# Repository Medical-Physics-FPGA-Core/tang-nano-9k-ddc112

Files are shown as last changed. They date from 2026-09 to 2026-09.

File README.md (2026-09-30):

# tang-nano-9k-ddc112

FPGA controller and Verilog/SystemVerilog readout implementation for the Texas Instruments DDC112 dual-channel 20-bit current-input ADC using the Sipeed Tang Nano 9K and Gowin FPGA.

This project is intended as a minimal working example for medical physics instrumentation and detector readout experiments.

## Status

- DVALID falling-edge detection confirmed
- DXMIT control implemented
- 40 DCLK pulse readout implemented
- DOUT response to photodiode light confirmed on oscilloscope
- CH1 / CH2 readout confirmed

## Hardware

- Sipeed Tang Nano 9K
- TI DDC112
- Photodiode input
- External level shifting may be required depending on logic levels

### Complete prototype
<p align="center">
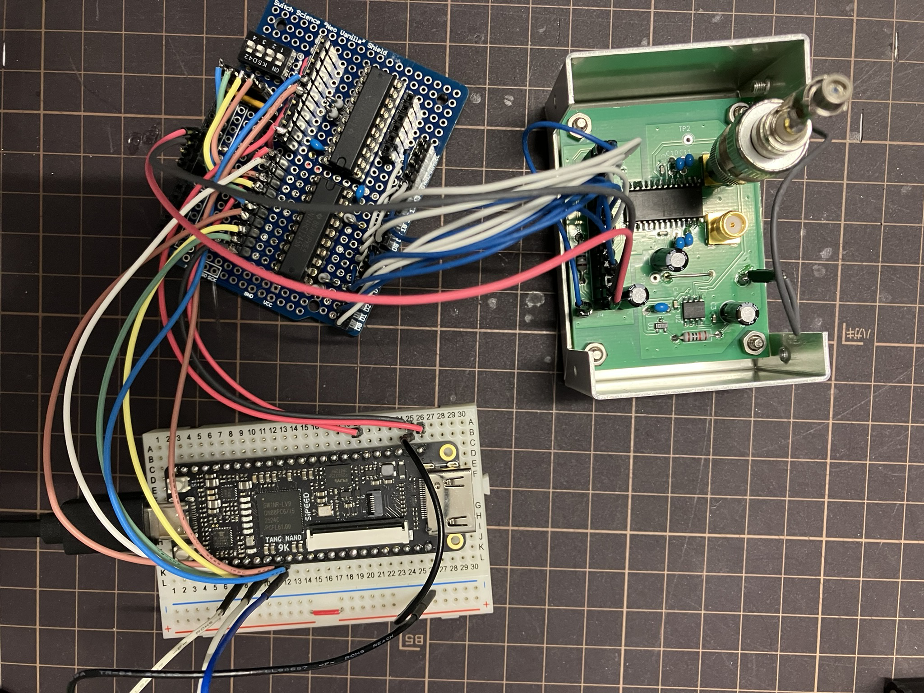
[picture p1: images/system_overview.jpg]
  
</p>
Tang Nano 9K FPGA controller connected to the custom DDC112 analog front-end.

### Custom DDC112 board
<p align="center">
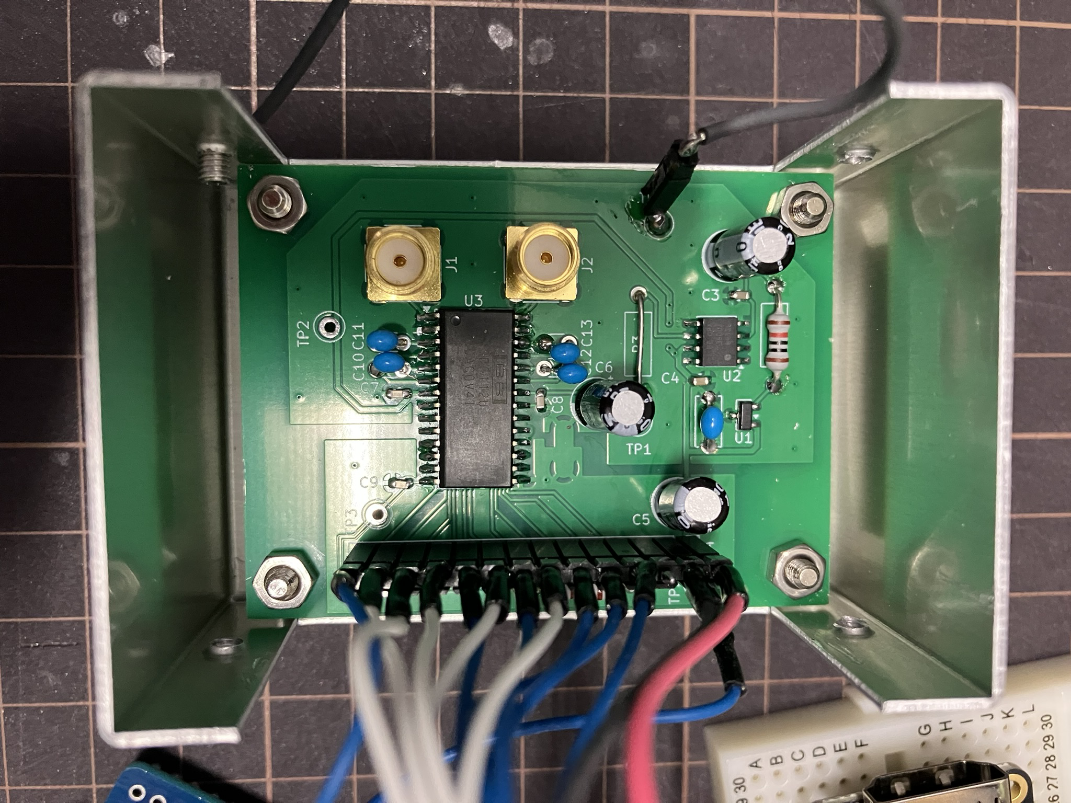
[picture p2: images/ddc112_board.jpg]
  
</p>
Custom PCB based on the Texas Instruments DDC112 dual-channel current-input ADC.

<!-- <img width="1536" height="2048" alt="IMG_5650" src="https://github.com/user-attachments/assets/f4167270-3db4-4d87-b112-6cfbf8c4dc7e" /> --->

## Notes

This repository contains experimental FPGA readout code developed for medical physics instrumentation research.

This is an experimental implementation, not an official TI reference design.
Timing and pin assignments should be verified for each hardware setup.

Constraint files are currently placed under src/ for simplicity.

## Demo

Real-time photodiode measurement using the Tang Nano 9K and DDC112.
[Watch the demonstration video on YouTube](https://youtu.be/cdM2_N08YOs)

## 5000-sample noise test

A 5000-sample open-input test at 0.5 ms integration and 50 pC full scale showed approximately **0.6 pA RMS equivalent input-current noise** after correcting the fixed A/B integrator offset, when the aluminum enclosure was connected to circuit GND.

Grounding the enclosure reduced the corrected RMS fluctuation by roughly **33–32×** compared with the isolated case.

See [`README_noise_test.md`](./docs/README_noise_test.md) for details.

The isolated-enclosure waveform contains a dominant \~60 Hz component in both channels, consistent with mains pickup; this component is strongly suppressed when the enclosure is grounded.

## Acknowledgements

The DDC112 analog front-end design was developed with reference to
Frédérik Berthiaume's Picoammeter project on Hackaday.io:
https://hackaday.io/project/176095-picoammeter

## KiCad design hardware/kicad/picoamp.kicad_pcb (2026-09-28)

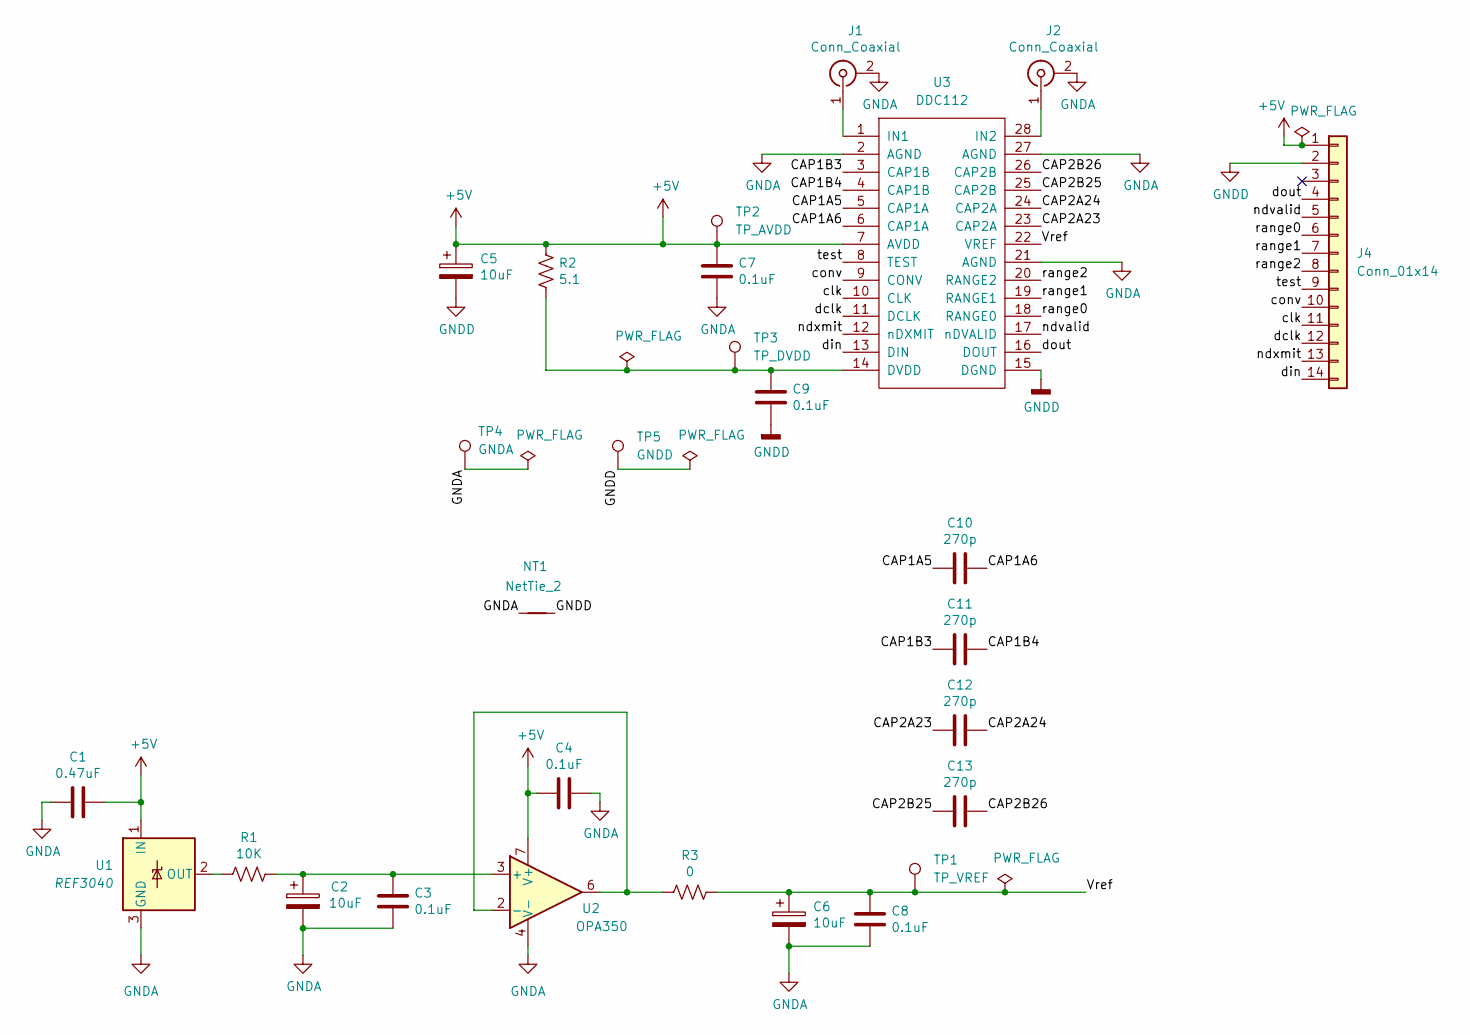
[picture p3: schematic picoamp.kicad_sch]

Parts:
C1: 0.47uF; C_Disc_D5.0mm_W2.5mm_P5.00mm
C2, C5, C6: 10uF; CP_Radial_D5.0mm_P2.00mm
C3, C4, C7, C8, C9: 0.1uF; C_0603_1608Metric
C10, C11, C12, C13: 270p; C_Disc_D3.0mm_W1.6mm_P2.50mm
J1, J2: Conn_Coaxial; SMA_Amphenol_132134_Vertical
J4: Conn_01x14; PinHeader_1x14_P2.54mm_Vertical
NT1: NetTie_2; NetTie-2_SMD_Pad2.0mm
R1: 10K; R_Axial_DIN0207_L6.3mm_D2.5mm_P10.16mm_Horizontal
R2: 5.1; R_Axial_DIN0207_L6.3mm_D2.5mm_P10.16mm_Horizontal
R3: 0; R_Axial_DIN0207_L6.3mm_D2.5mm_P10.16mm_Horizontal
TP1: TP_VREF; TestPoint_Loop_D1.80mm_Drill1.0mm_Beaded
TP2: TP_AVDD; TestPoint_Loop_D1.80mm_Drill1.0mm_Beaded
TP3: TP_DVDD; TestPoint_Loop_D1.80mm_Drill1.0mm_Beaded
TP4: GNDA; TestPoint_Loop_D1.80mm_Drill1.0mm_Beaded
TP5: GNDD; TestPoint_Loop_D1.80mm_Drill1.0mm_Beaded
U1: REF3040; SOT-23
U2: OPA350; SOIC-8_3.9x4.9mm_P1.27mm
U3: DDC112; SOIC-28W_7.5x17.9mm_P1.27mm

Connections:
+5V: C1.1, C4.2, C5.1, C7.1, J4.1, R2.1, TP2.1 (1_1), U1.1 (IN), U2.7 (V+), U3.7 (AVDD)
/CAP1A5: C10.2, U3.5 (CAP1A)
/CAP1A6: C10.1, U3.6 (CAP1A)
/CAP1B3: C11.2, U3.3 (CAP1B)
/CAP1B4: C11.1, U3.4 (CAP1B)
/CAP2A23: C12.2, U3.23 (CAP2A)
/CAP2A24: C12.1, U3.24 (CAP2A)
/CAP2B25: C13.2, U3.25 (CAP2B)
/CAP2B26: C13.1, U3.26 (CAP2B)
/Vref: C6.1, C8.1, R3.1, TP1.1 (1_1), U3.22 (VREF)
/clk: J4.11, U3.10 (CLK)
/conv: J4.10, U3.9 (CONV)
/dclk: J4.12, U3.11 (DCLK)
/din: J4.14, U3.13 (DIN)
/dout: J4.4, U3.16 (DOUT)
/ndvalid: J4.5, U3.17 (nDVALID)
/ndxmit: J4.13, U3.12 (nDXMIT)
/range0: J4.6, U3.18 (RANGE0)
/range1: J4.7, U3.19 (RANGE1)
/range2: J4.8, U3.20 (RANGE2)
/test: J4.9, U3.8 (TEST)
GNDA: C1.2, C2.2, C3.2, C4.1, C6.2, C7.2, C8.2, J1.2 (Ext), J2.2 (Ext), NT1.1, TP4.1 (1_1), U1.3 (GND), U2.4 (V-), U3.2 (AGND), U3.21 (AGND), U3.27 (AGND)
GNDD: C5.2, C9.2, J4.2, NT1.2, TP5.1 (1_1), U3.15 (DGND)
unnamed: J1.1 (In), U3.1 (IN1)
unnamed: J2.1 (In), U3.28 (IN2)
unnamed: R1.2, U1.2 (OUT)
unnamed: C2.1, C3.1, R1.1, U2.3 (+)
unnamed: R3.2, U2.2 (-), U2.6
unnamed: C9.1, R2.2, TP3.1 (1_1), U3.14 (DVDD)

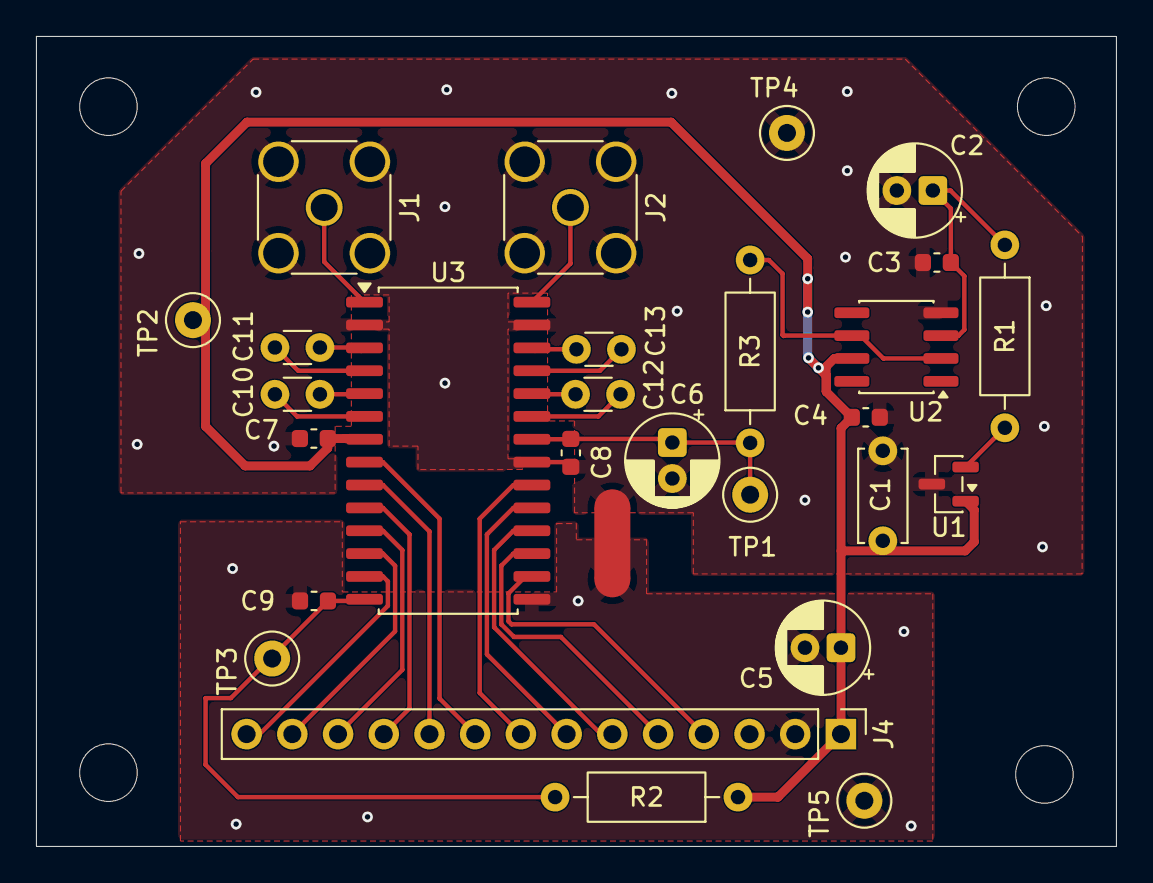
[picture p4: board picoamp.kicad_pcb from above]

Board: 2 copper layers, 60.0 x 45.0 mm, 28 parts (0 on the bottom side), 29 nets.

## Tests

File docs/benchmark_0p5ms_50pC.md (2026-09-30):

# Benchmark note: 0.5 ms / 50 pC / open input

## Purpose

To quantify the short-term noise of the DDC112 readout and to isolate the effect of connecting the aluminum enclosure to circuit ground.

## Conversion used

Nominal charge LSB:

`50 pC / 2^20 = 0.0477 fC/count`

Equivalent average current for 0.5 ms integration:

`0.0477 fC / 0.5 ms = 0.0954 pA/count`

## Results

| condition | channel | mean_count | A_B_offset_count | raw_sd_count | A_B_corrected_sd_count | equivalent_noise_fC_rms | equivalent_input_current_pA_rms |
|:---|:---|---:|---:|---:|---:|---:|---:|
| case_ground_connected | IN1 | 3759 | 145.137  | 72.8394 | 6.19079 | 0.2952 | 0.5904 |
| case_ground_connected | IN2 | 3747.16 | 81.8802 | 41.4282 | 6.31404 | 0.301077 | 0.602154 |
| case_ground_isolated  | IN1 | 3738.99 | 98.382  | 208.506  | 202.619 | 9.66165  | 19.3233 |
| case_ground_isolated  | IN2 | 3732.6  | 158.644  | 219.293  | 204.442 | 9.74853  | 19.4971 |

## Notes

- First 10 samples were excluded from the steady-state statistics.
- A/B correction was performed by subtracting the mean of each parity group independently.
- Open-input data are useful for evaluating pickup, shielding, leakage sensitivity, and short-term electronic stability.
- These data do not establish absolute current accuracy or linearity.

## 60 Hz pickup in the isolated-enclosure condition

An FFT of the steady-state open-input data (2 kS/s nominal sampling) shows a dominant peak at approximately **60.1 Hz** in both IN1 and IN2 when the enclosure is isolated from GND, with a weaker component near **120 Hz**. This supports the interpretation that the large common fluctuation is mainly mains-frequency pickup rather than independent channel noise.

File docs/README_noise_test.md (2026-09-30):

# DDC112 noise test: effect of enclosure grounding

This note documents a 5000-sample noise test of a custom DDC112 + Tang Nano 9K readout board.

## Test conditions

- ADC: Texas Instruments DDC112
- Input condition: open input
- Integration time: 0.5 ms
- Full-scale range: 50 pC
- Acquisition: 5000 consecutive samples
- Channels: IN1 and IN2
- Compared conditions:
  1. Aluminum enclosure connected to circuit GND
  2. Aluminum enclosure electrically isolated from circuit GND

For steady-state statistics, the first 10 samples (5 ms) were excluded.

## Main result

After correcting the fixed A/B integrator offset separately for even and odd samples, the RMS fluctuation was:

| Condition | Channel | A/B-corrected SD (count) | Equivalent charge noise (fC RMS) | Equivalent input-current noise (pA RMS) |
|---|---:|---:|---:|---:|
| Enclosure connected to GND | IN1 | 6.19 | 0.295 | 0.59 |
| Enclosure connected to GND | IN2 | 6.31 | 0.301 | 0.60 |
| Enclosure isolated from GND | IN1 | 202.6 | 9.66 | 19.3 |
| Enclosure isolated from GND | IN2 | 204.4 | 9.75 | 19.5 |

Grounding the enclosure reduced the A/B-corrected RMS fluctuation by approximately **33× (IN1)** and **32× (IN2)**.

At a nominal 50 pC full scale,

- 1 count = 0.0477 fC
- 1 count over 0.5 ms = 0.0954 pA

Therefore the grounded configuration achieved approximately **0.6 pA RMS equivalent input-current noise** in both channels.

> This is a short-term noise figure derived from an open-input measurement. It is not a calibrated absolute-current accuracy specification.

## Time-series comparison

### Enclosure connected to GND

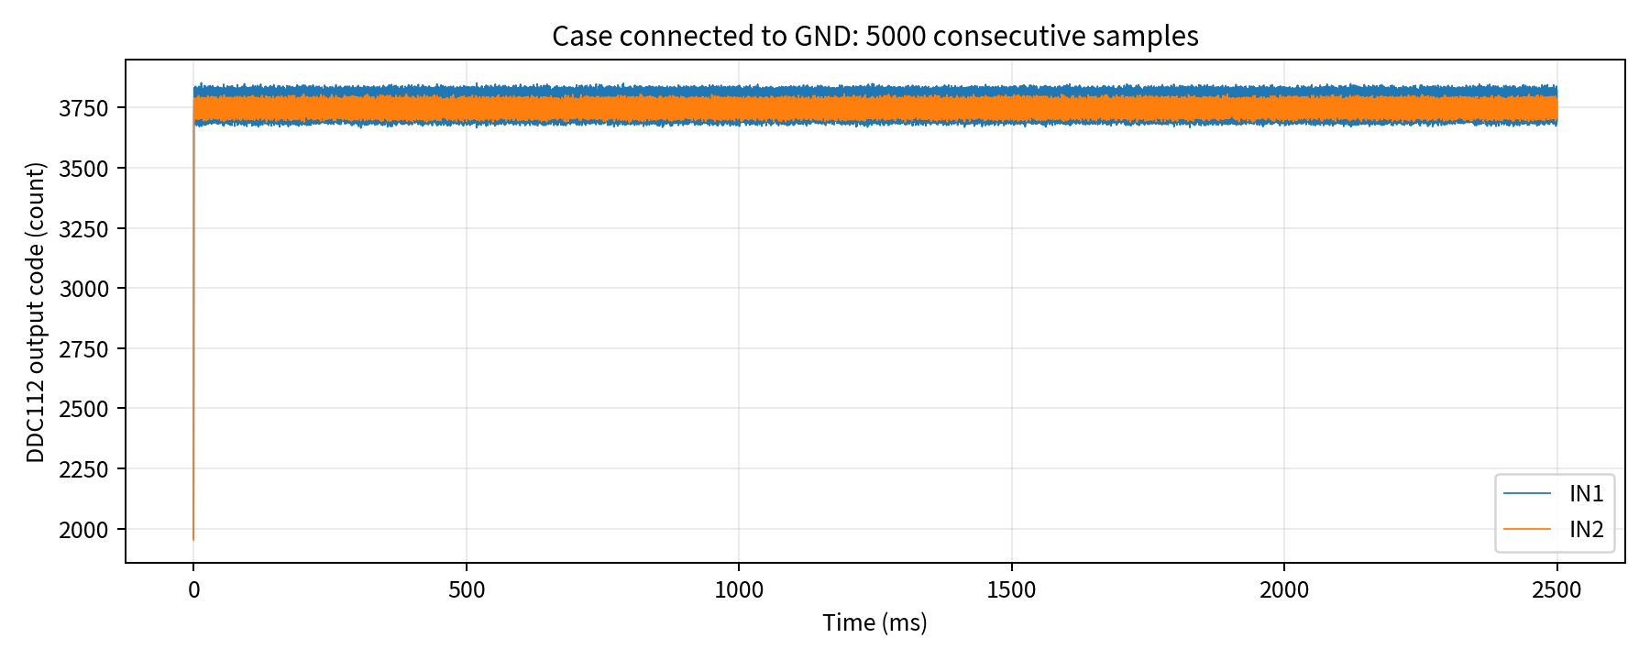
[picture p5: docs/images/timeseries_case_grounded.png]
Grounded enclosure


### Enclosure isolated from GND

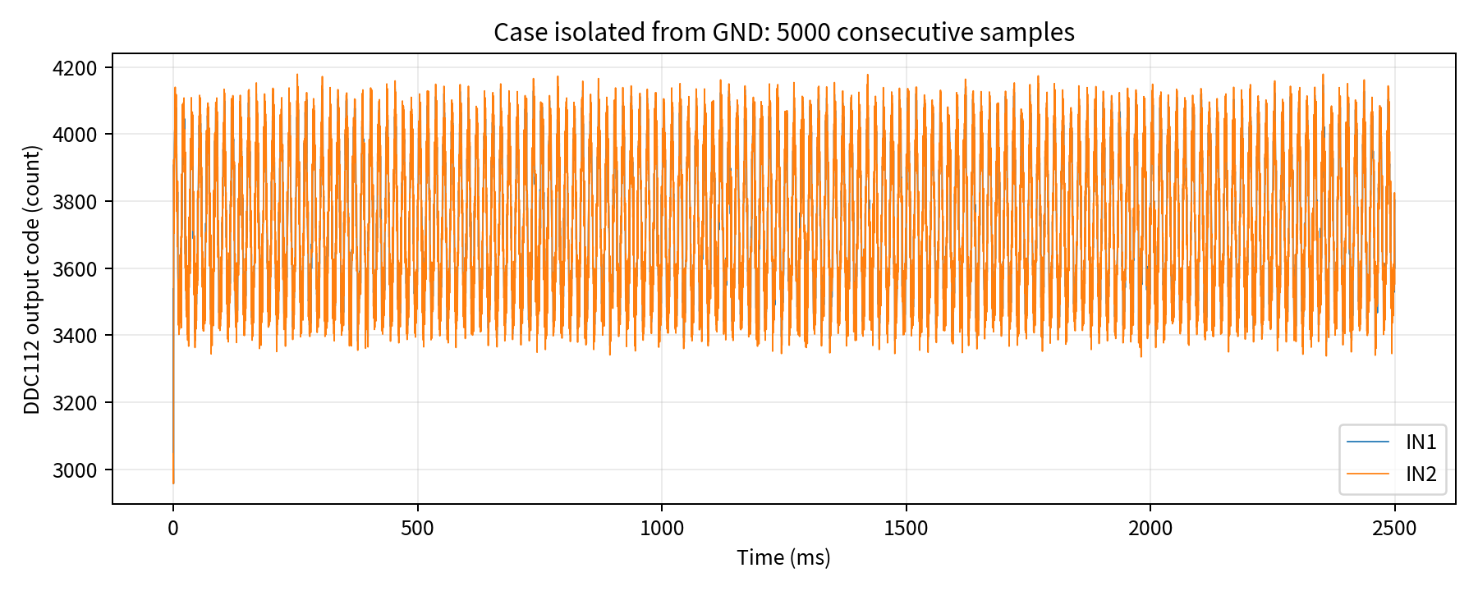
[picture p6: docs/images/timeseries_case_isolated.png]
Isolated enclosure


The isolated case shows large common excursions in IN1 and IN2. This suggests that much of the additional fluctuation is externally coupled/common-mode interference rather than independent channel noise.

A frequency-domain check of the same isolated data shows a dominant component at approximately **60.1 Hz** in both channels, with a smaller component near **120 Hz**. This is consistent with pickup from the local 60 Hz mains environment. After connecting the aluminum enclosure to GND, the pronounced 60 Hz component is no longer dominant.

## A/B integrator offset

The DDC112 uses two alternating integrators per input. A fixed difference between the A and B paths appears as an even/odd two-state pattern.

In the grounded measurement, the A/B mean separation was:

- IN1: 145.1 counts
- IN2: 81.9 counts

The raw SD is therefore not a good estimate of random noise unless the two integrator paths are calibrated separately.

## Interpretation

The result demonstrates three practical points:

1. **The enclosure-ground connection is essential** for low-noise operation in this setup.
2. **A/B integrator calibration matters** because the fixed alternating offset can dominate the uncorrected standard deviation.
3. With the enclosure grounded and the A/B offset removed, the present system shows **sub-pA RMS short-term repeatability** at 0.5 ms integration.

The RMS noise corresponds to roughly **17.4–17.3 bits of dynamic range referenced to the 20-bit full scale**, but this should not be called ADC ENOB because linearity, gain error, drift, and absolute calibration are not included.

## Relation to the DDC112 datasheet

The DDC112 datasheet specifies a 20-bit continuous integrating architecture and emphasizes careful analog grounding, shielding around the high-impedance inputs, short analog connections, and separation of digital signals from analog inputs.

The datasheet also gives a typical low-level input-noise figure of 3.2 ppm FSR RMS under a different test condition (250 pC range, 0 pF sensor capacitance, 500 µs integration). Because the range and board conditions differ, the value should not be compared directly with the present 50 pC measurement.

Reference: Texas Instruments, *DDC112 Dual Current Input 20-Bit Analog-to-Digital Converter*, SBAS085B.

## Files

- `images/timeseries_case_grounded.png`
- `images/timeseries_case_isolated.png`
- `data/summary_metrics.csv`

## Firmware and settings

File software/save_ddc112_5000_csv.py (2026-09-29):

import csv
import re
from datetime import datetime

import serial

# ============================================================
# User settings
# ============================================================

PORT = "COM5"          # Change this to the COM port used by Tang Nano 9K / BL702
BAUD = 115200
NUM_SAMPLES = 5_000
TINT_MS = 0.5

# Expected FPGA UART line:
#   IN2=0AED9 IN1=0AD51
pattern = re.compile(r"^IN2=([0-9A-Fa-f]{5}) IN1=([0-9A-Fa-f]{5})$")


def main():
    timestamp = datetime.now().strftime("%Y%m%d_%H%M%S")
    filename = f"ddc112_5000samples_{timestamp}.csv"

    print(f"Opening {PORT} at {BAUD} bit/s...")

    count = 0

    with serial.Serial(PORT, BAUD, timeout=1) as ser, \
            open(filename, "w", newline="", encoding="utf-8") as f:

        # Discard any old bytes that were already waiting in the PC serial buffer.
        ser.reset_input_buffer()

        print("Serial port is ready.")
        print("Now reset or reprogram the FPGA.")
        print("The FPGA captures 5,000 samples first (2.5 s at TINT = 0.5 ms),")
        print("then transmits the stored data over UART.")
        print("Press Ctrl+C to stop.\n")

        writer = csv.writer(f)
        writer.writerow([
            "sample",
            "nominal_time_ms",
            "parity",
            "IN1_hex",
            "IN1_dec",
            "IN2_hex",
            "IN2_dec",
        ])

        try:
            while count < NUM_SAMPLES:
                raw = ser.readline()

                if not raw:
                    continue

                line = raw.decode("ascii", errors="ignore").strip()
                m = pattern.match(line)

                if not m:
                    print(f"Ignored: {line}")
                    continue

                in2_hex = m.group(1).upper()
                in1_hex = m.group(2).upper()

                in2_dec = int(in2_hex, 16)
                in1_dec = int(in1_hex, 16)

                writer.writerow([
                    count,
                    count * TINT_MS,
                    "even" if (count % 2 == 0) else "odd",
                    in1_hex,
                    in1_dec,
                    in2_hex,
                    in2_dec,
                ])

                count += 1

                if count % 1000 == 0:
                    print(f"{count:5d} / {NUM_SAMPLES} samples received")

        except KeyboardInterrupt:
            print("\nStopped by user.")

    print(f"\nSaved {count} samples to:")
    print(filename)

    if count == NUM_SAMPLES:
        print("Acquisition completed successfully.")


if __name__ == "__main__":
    main()

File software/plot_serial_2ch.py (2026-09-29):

import serial
import time
import re
from collections import deque

import matplotlib.pyplot as plt
import matplotlib.animation as animation

# ===== set =====
PORT = "COM5"        # my COM number
BAUD = 115200       # same with FPGA/BL702
MAX_POINTS = 120    # for about 60s if 0.5s interval

ser = serial.Serial(PORT, BAUD, timeout=1)

t_data = deque(maxlen=MAX_POINTS)
in1_data = deque(maxlen=MAX_POINTS)
in2_data = deque(maxlen=MAX_POINTS)

start_time = time.time()

fig, ax = plt.subplots()
line_in1, = ax.plot([], [], label="IN1")
line_in2, = ax.plot([], [], label="IN2")

ax.set_xlabel("Time [s]")
ax.set_ylabel("ADC code")
ax.set_ylim(0, 0x110000)   # fix to 20 bit ADC code
#ax.set_ylim(0, 0x2FFF)
ax.grid(True)
ax.legend()

# 例: IN2=0AED9 IN1=0AD51
pattern = re.compile(r"IN2=([0-9A-Fa-f]+)\s+IN1=([0-9A-Fa-f]+)")

def parse_line(line: str):
    line = line.strip()

    m = pattern.search(line)
    if not m:
        print("Parse error:", line)
        return None

    in2_hex = m.group(1)
    in1_hex = m.group(2)

    in2 = int(in2_hex, 16)
    in1 = int(in1_hex, 16)

    return in1, in2

def update(frame):
    while ser.in_waiting:
        raw = ser.readline()

        try:
            line = raw.decode("ascii", errors="ignore")
        except UnicodeDecodeError:
            continue

        result = parse_line(line)
        if result is None:
            continue

        in1, in2 = result
        t = time.time() - start_time

        t_data.append(t)
        in1_data.append(in1)
        in2_data.append(in2)

        print(f"{t:8.2f} s  IN1={in1:6d}  IN2={in2:6d}")

    if len(t_data) > 0:
        line_in1.set_data(t_data, in1_data)
        line_in2.set_data(t_data, in2_data)

        ax.set_xlim(max(0, t_data[0]), max(10, t_data[-1]))

    return line_in1, line_in2

ani = animation.FuncAnimation(fig, update, interval=100, blit=False)

plt.show()

ser.close()
